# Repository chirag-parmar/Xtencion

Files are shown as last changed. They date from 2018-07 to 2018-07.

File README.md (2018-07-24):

#### The Design Methodology:
* The Xtencion band is equipped with a SHARP IR distance sensor to detect the different swipe gestures  and a 6DOF gyro module to read the wrist gestures. The band recognizes either individual gestures or a combination of them.
* After recognition it either navigates through the menu or triggers an external event based on the patter of the gestures. This way we provide a hassle free usability for the user.
* Since it is powered by a ESP32 (which has WiFi and Bluetooth onboard) connecting to other IoT devices is a breeze. The band controls other devices through a third-party service called IFTTT.
* IFTTT (stands for If This Then That) is a platform that enables interface between various devices. We plan to deploy Xtencion “Recipe” Blocks on their platform so that the user can customise external events. This way we provide extended functionality to the user.
* The band is powered by bendable lithium ion batteries which ensure maximum packing density and greater battery capacity. Such use of technology eliminates the biggest drawback of current smartwatches.

#### The Features:
* It is gesture controlled, so no more tapping the wrong thing and wasting time going back and attempting to tap again.
* It will reduce battery usage by nearly 50% by removing the touchscreen. The device will, additionally, use low power sensors.
* The device will have virtually an infinite number of features since new gestures can be added and each gesture can be customised.

#### The 3P Design Specifications:
* Power: It will last about 6 days without needing a charge according to our calculation.
* Precision: It has a range of 4 cm to 30 cm with an accuracy of 1mm.
* Protocols: The device uses HTTP to communicate with IoT devices and uses Bluetooth to get location data for location based gestures.

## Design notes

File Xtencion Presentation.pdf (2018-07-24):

# Xtencion

### A smarter smartwatch

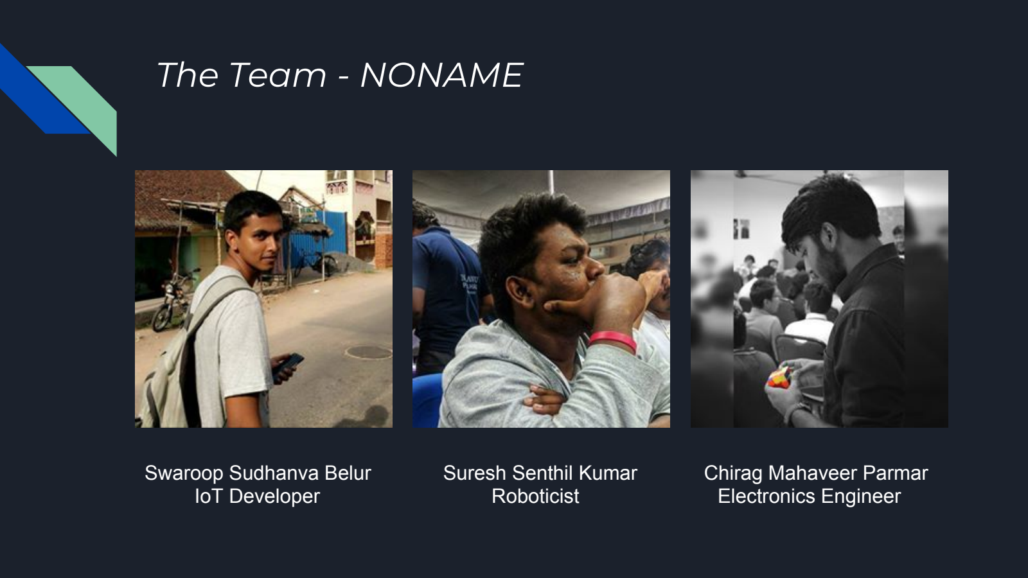
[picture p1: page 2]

The Team - NONAME

Swaroop Sudhanva Belur | Suresh Senthil Kumar | Chirag Mahaveer Parmar
IoT Developer | Roboticist | Electronics Engineer

## Connected Wearables

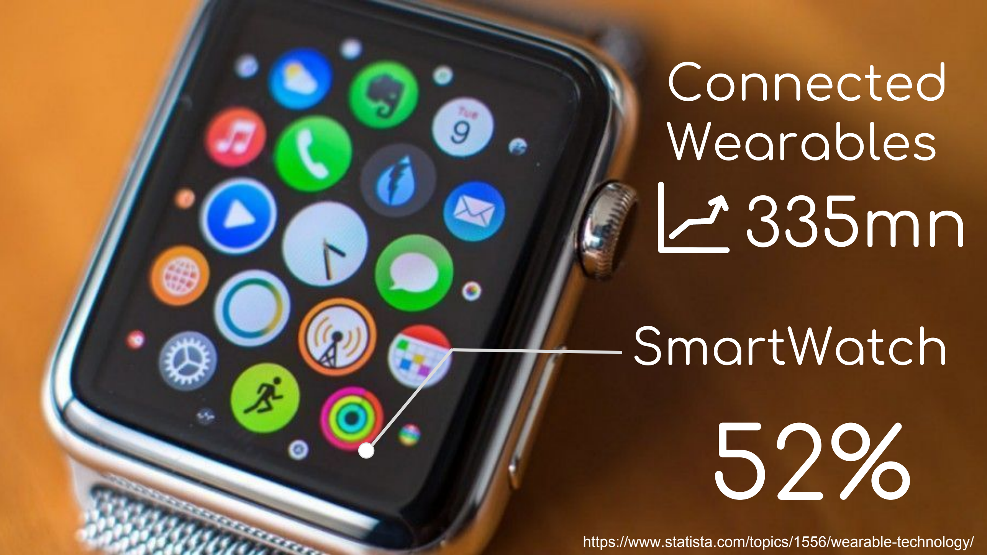
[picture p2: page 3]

## SmartWatch

335mn

52%

https://www.statista.com/topics/1556/wearable-technology/

The Problems with Smart Watches

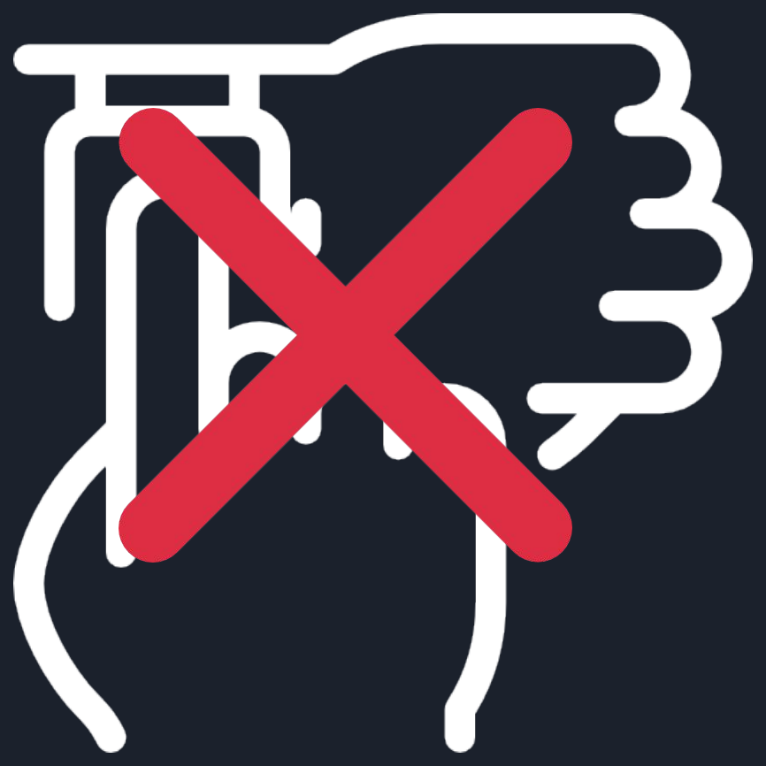
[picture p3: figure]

1

Difficult to navigate

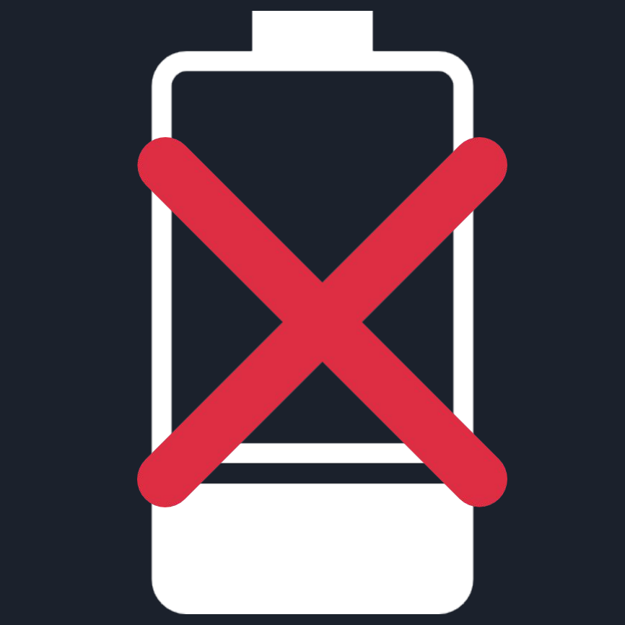
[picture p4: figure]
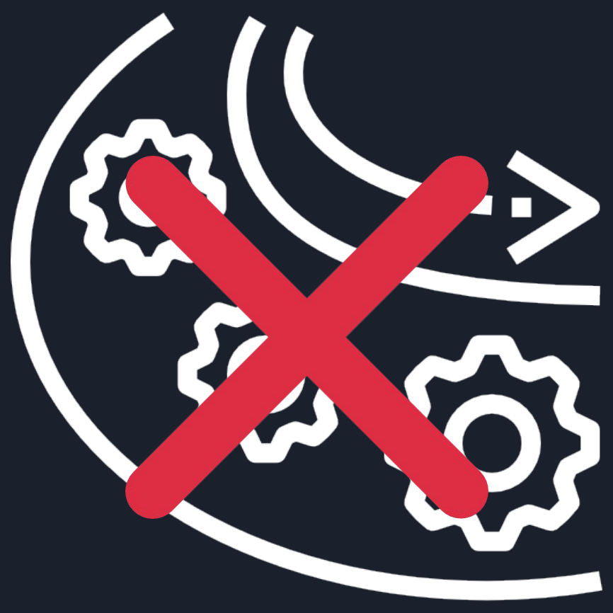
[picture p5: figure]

interface | 2 | Very - Short Battery Life | 3 | Missing Distinct Features compared to SmartPhones

https://www.cnet.com/videos/top-5-reasons-smartwatches-dont-sell/

The Validation - User Interviews

“My smartwatch is just like my phone, why did I waste money for something that I already have. I expected my
smartwatch to have extra
features in it”
- Mr. Rajesh, Self-Employed Entrepreneur

“It’s difficult to navigate through the menu on such a small screen. I would opt for a smart watch with buttons on it for easier use.”

- Ms. Lalitha, Fitness Freak

The Question

How can we make smartwatches a better tool and a better user experience for the end customer?

The Solution

We have built Xtencion, an intelligent wrist wear that has unparalleled functionality, improves the users’ productivity and efficiency while at the same time does not boggle the user with complicated user interfaces.

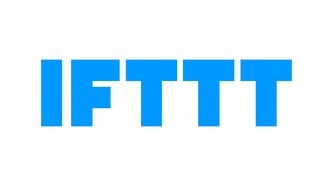
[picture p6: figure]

# How do we do it?

The Algorithm

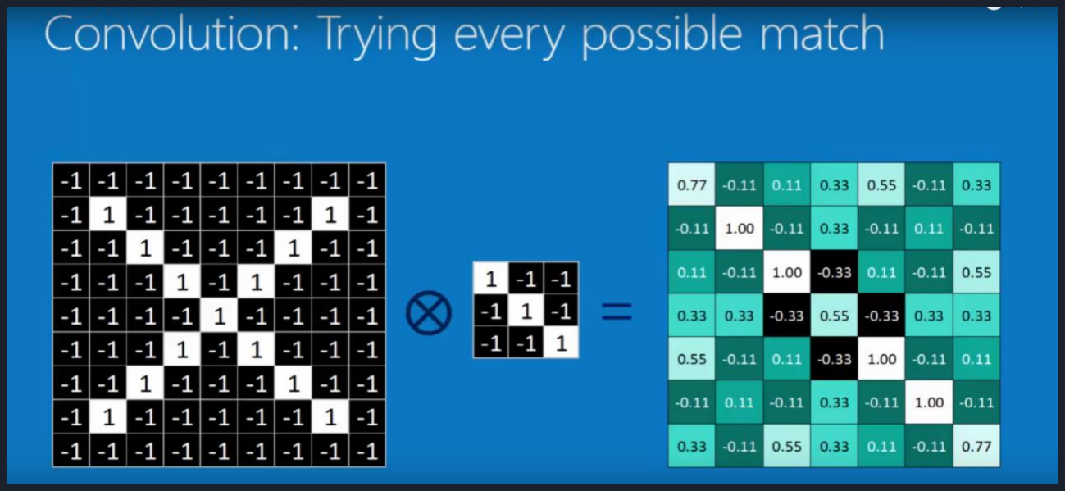
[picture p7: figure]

It is a signal processing
algorithm that uses a form of machine learning to
detect the hand gestures
using a predetermined
kernel. We use this kernel by performing convolution
of itself and the signal from the sharp rangefinder
sensor.

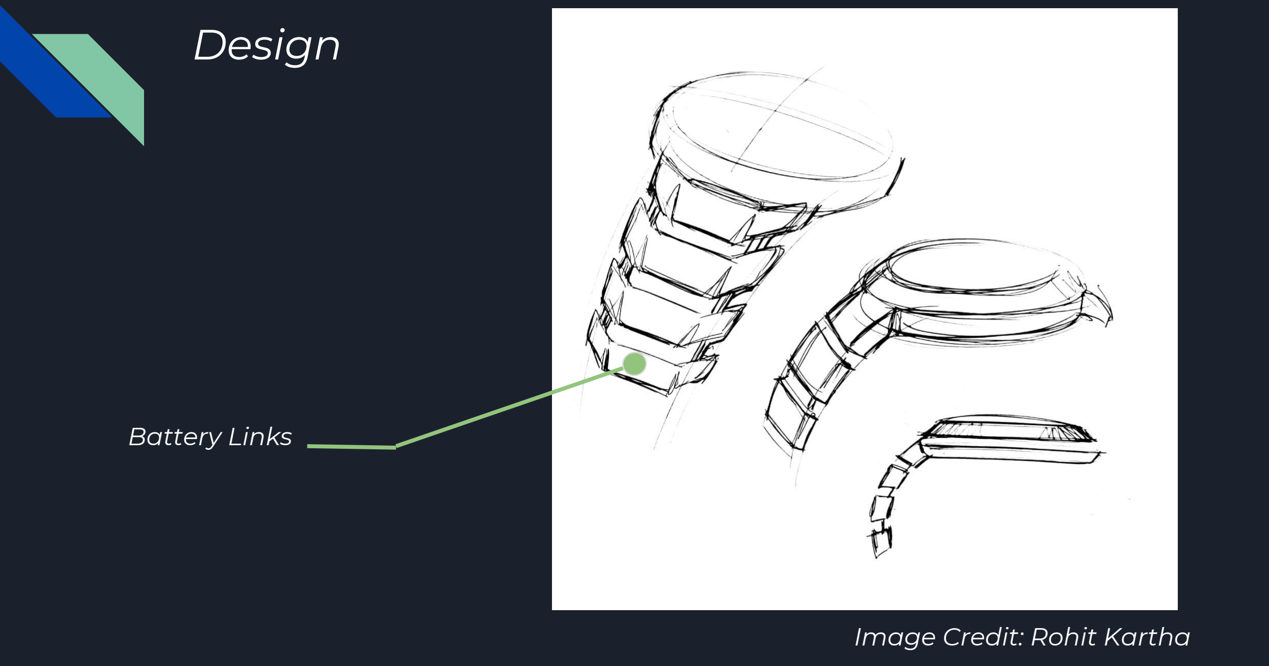
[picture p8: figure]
Design; Battery Links; Image Credit: Rohit Kartha

The 3X Design Features

It is gesture controlled, so no more tapping the wrong thing and wasting time going back and attempting to tap again.

It will reduce battery usage by nearly 10% by removing the touchscreen. The device will, additionally, use low power sensors.

The gestures are location based and time based so the user doesn’t have to remember different patterns of gestures

XTENDED USABILITY

XTENDED BATTERY

XTENDED FUNCTIONALITY

The 3P Design Specifications

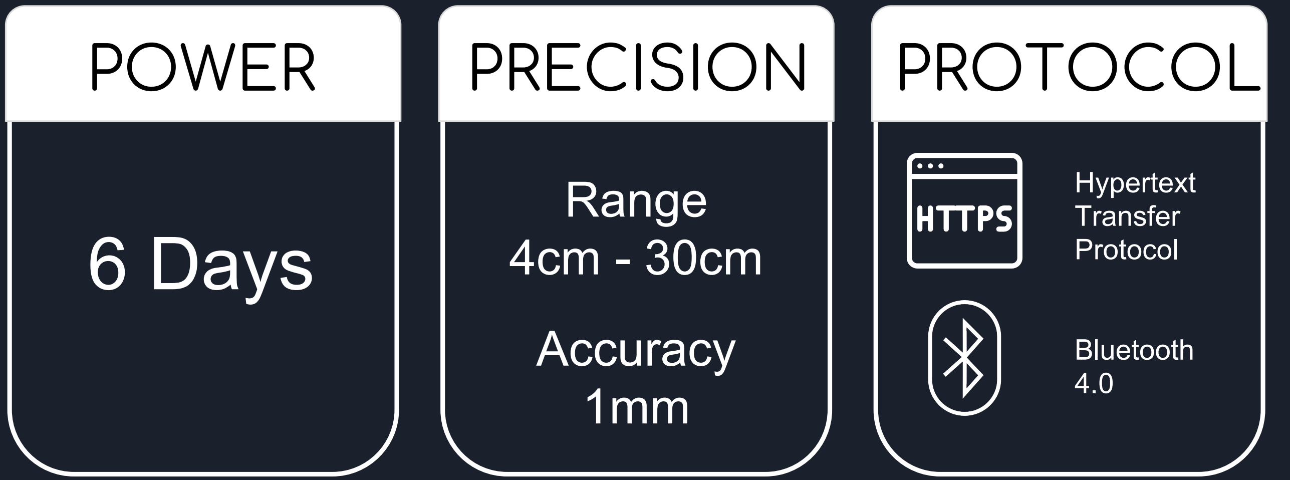
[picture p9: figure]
POWER; PRECISION; PROTOCOL; Range 4cm - 30cm; Accuracy 1mm; 6 Days; Hypertext Transfer Protocol; Bluetooth 4.0

* The price represent the design cost and not the cost of the product itself. If you were to design on your own it would cost you the above mentioned price.

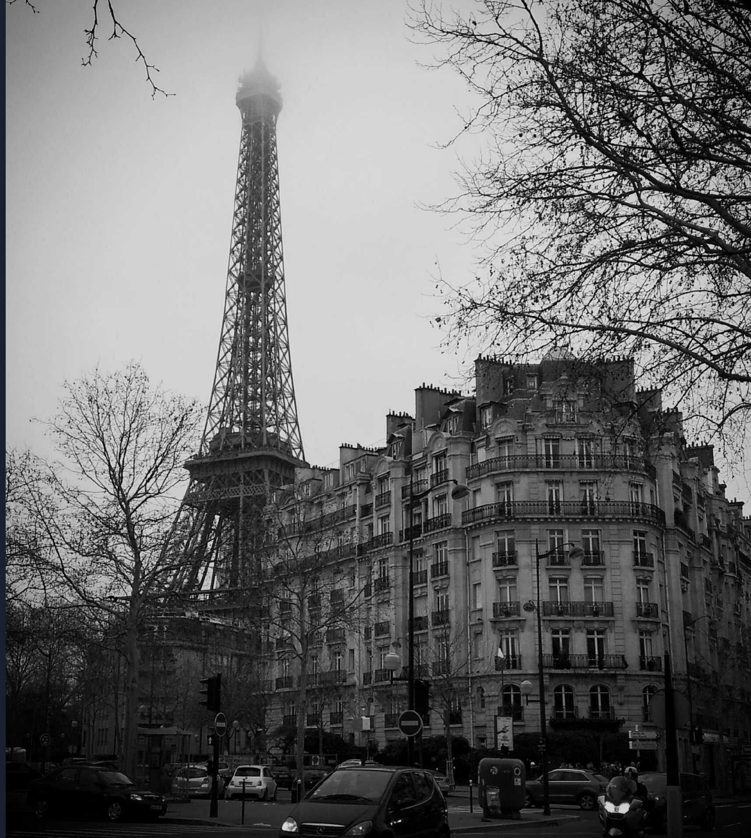
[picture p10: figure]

Thank You

Ask me anything!

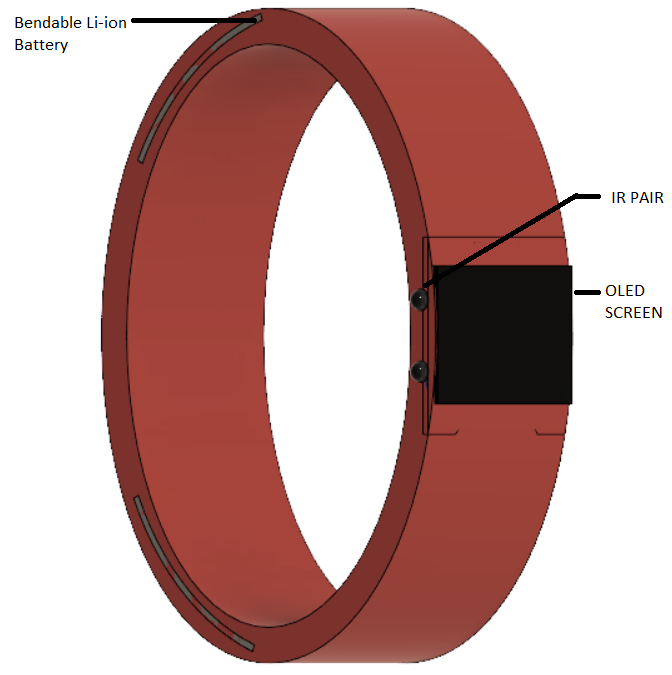
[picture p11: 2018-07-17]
images/Angled View Whole.png

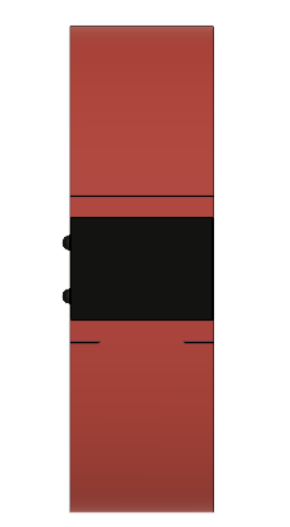
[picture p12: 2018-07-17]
images/Angled View IR.png

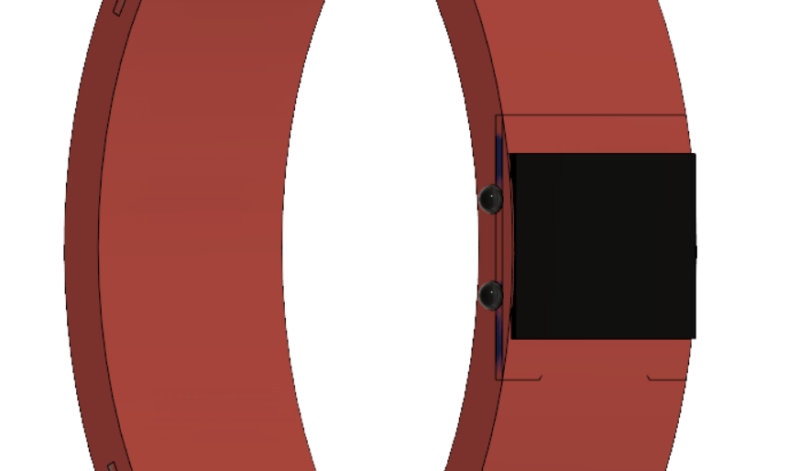
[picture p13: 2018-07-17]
images/Front View.png

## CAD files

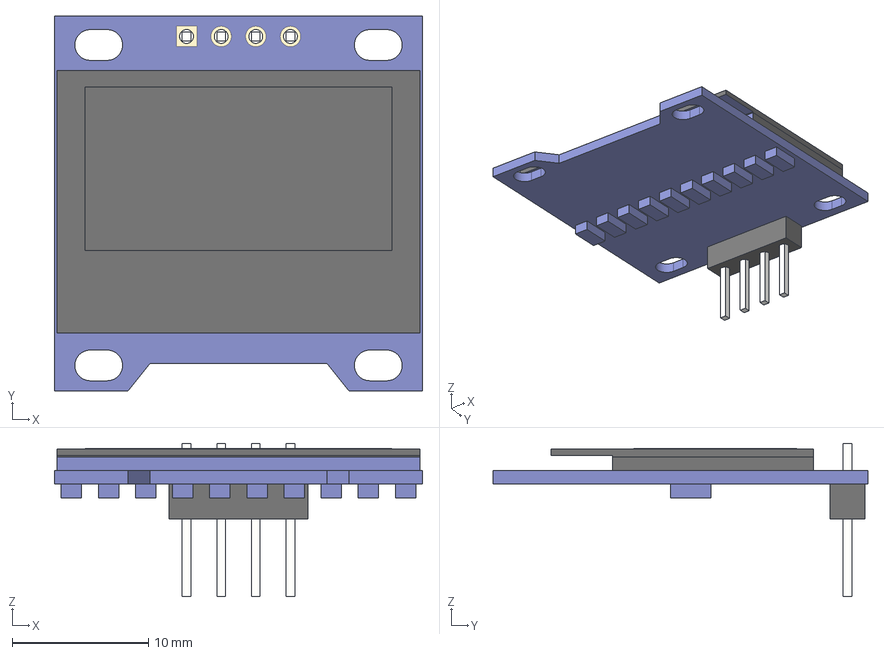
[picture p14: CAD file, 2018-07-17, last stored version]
128x64Oled v3.iges
27.0 x 27.5 x 11.2 mm

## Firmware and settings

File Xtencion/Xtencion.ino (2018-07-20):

#include <Wire.h>
#include "Kalman.h"
#include "SSD1306Wire.h"
#include <Adafruit_ADS1015.h>

//#define RESTRICT_PITCH // Comment out to restrict roll to ±90deg instead - please read: http://www.freescale.com/files/sensors/doc/app_note/AN3461.pdf

//-----------------Create Kalman Instances-------------------------//
Kalman kalmanX;
Kalman kalmanY;

//---------------------IMU constants and variables-----------------//
double accX, accY, accZ;
double gyroX, gyroY, gyroZ;
int16_t tempRaw;

double gyroXangle, gyroYangle; // Angle calculate using the gyro only
double compAngleX, compAngleY; // Calculated angle using a complementary filter
double kalAngleX, kalAngleY; // Calculated angle using a Kalman filter

uint32_t timer;
uint8_t i2cData[14]; // Buffer for I2C data

const uint8_t IMUAddress = 0x68; // AD0 is logic low on the PCB
const uint16_t I2C_TIMEOUT = 1000; // Used to check for errors in I2C communication

//---------------Sharp Sensor constants and Variables-------------//
Adafruit_ADS1115 ads;
int16_t sharp_adc;
float voltage;
double distance;
unsigned long distancetimer;
const int num_samples = 21;
int interval = 200;
double dist_q[num_samples];

//----------------OLED Display variables and constants-----------//
SSD1306Wire  display(0x3c, 0, 2);
unsigned long displaytimer;
//################################################ SETUP #####################################################//
void setup() {

  //----------------------Communication Setup ----------------------//
  Serial.begin(115200);
  Wire.begin(0, 2);
  Wire.setClock(400000L);

  //---------------------------IMU Setup---------------------------//
  i2cData[0] = 7; // Set the sample rate to 1000Hz - 8kHz/(7+1) = 1000Hz
  i2cData[1] = 0x00; // Disable FSYNC and set 260 Hz Acc filtering, 256 Hz Gyro filtering, 8 KHz sampling
  i2cData[2] = 0x00; // Set Gyro Full Scale Range to ±250deg/s
  i2cData[3] = 0x00; // Set Accelerometer Full Scale Range to ±2g
  while (i2cWrite(IMUAddress, 0x19, i2cData, 4, false)); // Write to all four registers at once
  while (i2cWrite(IMUAddress, 0x6B, 0x01, true)); // PLL with X axis gyroscope reference and disable sleep mode

  while (i2cRead(IMUAddress, 0x75, i2cData, 1));
  if (i2cData[0] != 0x71) { // Read "WHO_AM_I" register
    Serial.print(F("Error reading sensor"));
    while (1);
  }

  delay(100); // Wait for sensor to stabilize

  //----------------------Kalman Filter Setup---------------------//
  
  /* Set kalman and gyro starting angle */
  while (i2cRead(IMUAddress, 0x3B, i2cData, 6));
  accX = (i2cData[0] << 8) | i2cData[1];
  accY = (i2cData[2] << 8) | i2cData[3];
  accZ = (i2cData[4] << 8) | i2cData[5];
  
  #ifdef RESTRICT_PITCH // Eq. 25 and 26
    double roll  = atan2(accY, accZ) * RAD_TO_DEG;
    double pitch = atan(-accX / sqrt(accY * accY + accZ * accZ)) * RAD_TO_DEG;
  #else // Eq. 28 and 29
    double roll  = atan(accY / sqrt(accX * accX + accZ * accZ)) * RAD_TO_DEG;
    double pitch = atan2(-accX, accZ) * RAD_TO_DEG;
  #endif

  kalmanX.setAngle(roll); // Set starting angle
  kalmanY.setAngle(pitch);
  gyroXangle = roll;
  gyroYangle = pitch;
  compAngleX = roll;
  compAngleY = pitch;

  timer = micros();

  //-----------------------ADS 1115 Setup---------------------------//
  ads.begin();
  distancetimer = millis();
  for (int i=0;i<num_samples;i++)
  dist_q[i]=0.0;
  
  //-----------------------OLED Display Setup-----------------------//
  display.init();
  display.flipScreenVertically();
  display.setFont(ArialMT_Plain_10);
  displaytimer = millis();
}

//########################################## LOOP #########################################//
void loop() {
  //-----------------------Read IMU data--------------------//
  while (i2cRead(IMUAddress, 0x3B, i2cData, 14));
  accX = ((i2cData[0] << 8) | i2cData[1]) + 4000;
  accY = ((i2cData[2] << 8) | i2cData[3]) + 3500;
  accZ = ((i2cData[4] << 8) | i2cData[5]);
  tempRaw = (i2cData[6] << 8) | i2cData[7];
  gyroX = (i2cData[8] << 8) | i2cData[9];
  gyroY = (i2cData[10] << 8) | i2cData[11];
  gyroZ = (i2cData[12] << 8) | i2cData[13];

  //-------------------------Manipulate Data and Kalman Filter---------------------------//
  double dt = (double)(micros() - timer) / 1000000; // Calculate delta time
  timer = micros();

  #ifdef RESTRICT_PITCH // Eq. 25 and 26
    double roll  = atan2(accY, accZ) * RAD_TO_DEG;
    double pitch = atan(-accX / sqrt(accY * accY + accZ * accZ)) * RAD_TO_DEG;
  #else // Eq. 28 and 29
    double roll  = atan(accY / sqrt(accX * accX + accZ * accZ)) * RAD_TO_DEG;
    double pitch = atan2(-accX, accZ) * RAD_TO_DEG;
  #endif

  double gyroXrate = gyroX / 131.0; // Convert to deg/s
  double gyroYrate = gyroY / 131.0; // Convert to deg/s

  #ifdef RESTRICT_PITCH
    // This fixes the transition problem when the accelerometer angle jumps between -180 and 180 degrees
    if ((roll < -90 && kalAngleX > 90) || (roll > 90 && kalAngleX < -90)) {
      kalmanX.setAngle(roll);
      compAngleX = roll;
      kalAngleX = roll;
      gyroXangle = roll;
    } else
      kalAngleX = kalmanX.getAngle(roll, gyroXrate, dt); // Calculate the angle using a Kalman filter

    if (abs(kalAngleX) > 90)
      gyroYrate = -gyroYrate; // Invert rate, so it fits the restriced accelerometer reading
    kalAngleY = kalmanY.getAngle(pitch, gyroYrate, dt);
  #else
    // This fixes the transition problem when the accelerometer angle jumps between -180 and 180 degrees
    if ((pitch < -90 && kalAngleY > 90) || (pitch > 90 && kalAngleY < -90)) {
      kalmanY.setAngle(pitch);
      compAngleY = pitch;
      kalAngleY = pitch;
      gyroYangle = pitch;
    } else
      kalAngleY = kalmanY.getAngle(pitch, gyroYrate, dt); // Calculate the angle using a Kalman filter

    if (abs(kalAngleY) > 90)
      gyroXrate = -gyroXrate; // Invert rate, so it fits the restriced accelerometer reading
    kalAngleX = kalmanX.getAngle(roll, gyroXrate, dt); // Calculate the angle using a Kalman filter
  #endif

  gyroXangle += gyroXrate * dt; // Calculate gyro angle without any filter
  gyroYangle += gyroYrate * dt;
  //gyroXangle += kalmanX.getRate() * dt; // Calculate gyro angle using the unbiased rate
  //gyroYangle += kalmanY.getRate() * dt;

  compAngleX = 0.93 * (compAngleX + gyroXrate * dt) + 0.07 * roll; // Calculate the angle using a Complimentary filter
  compAngleY = 0.93 * (compAngleY + gyroYrate * dt) + 0.07 * pitch;

  // Reset the gyro angle when it has drifted too much
  if (gyroXangle < -180 || gyroXangle > 180)
    gyroXangle = kalAngleX;
  if (gyroYangle < -180 || gyroYangle > 180)
    gyroYangle = kalAngleY;

  //-------------------------Print Calculated Values----------------------------------//
//    Serial.print(accX); Serial.print("\t");
//    Serial.print(accY); Serial.print("\t");
//    Serial.print(accZ); Serial.print("\t");
//
//    Serial.print(roll); Serial.print("\t");
//    Serial.print(gyroXangle); Serial.print("\t");
//    Serial.print(compAngleX); Serial.print("\t");
//    Serial.print(kalAngleX); Serial.print("\t");
//
//    Serial.print("\t");
//
//    Serial.print(pitch); Serial.print("\t");
//    Serial.print(gyroYangle); Serial.print("\t");
//    Serial.print(compAngleY); Serial.print("\t");
//    Serial.print(kalAngleY); Serial.print("\t");
//
//    Serial.print("\t");
//
//    double temperature = (double)tempRaw / 340.0 + 36.53;
//    Serial.print(temperature); Serial.print("\t");
//
//    Serial.print("\t");
    
    
    sharp_adc = ads.readADC_SingleEnded(0);
    voltage = sharp_adc*0.1875/1000;
    distance = 13*pow(voltage,-1);
    if (((millis() - distancetimer) > interval) && distance > 4 && distance < 20){
      for (int  i= (num_samples-1); i>0; i--){
        dist_q[i] = dist_q[i-1];
      }
      dist_q[0] = distance;
      Serial.print("[ ");
      for (int i = (num_samples-1); i>= 0; i--){
        Serial.print(dist_q[i]);
        if (i!=0)Serial.print(", "); 
      }
      Serial.print(" ]");Serial.println("");
      
      double max = dist_q[0];
      int max_pos = 0;
      for (int i = 0; i < num_samples; i++)
      {
       if (dist_q[i] > max){
          max = dist_q[i];
          max_pos = i;
       }
      }
      
      double diff_forward = 0.0;
      double diff_backward = 0.0;
      Serial.print(diff_forward);Serial.print("\t");
      Serial.print(diff_backward);Serial.print("\t");
      //back swipe
      for (int i=0; i<max_pos ; i++){
        diff_backward += (dist_q[i+1] - dist_q[i]);
      }

      //forward swipe
      for (int i=max_pos; i<num_samples; i++){
        diff_forward += (dist_q[i-1] - dist_q[i]);
      }

      if (diff_forward > 4 && diff_backward > 4 && diff_forward < 7 && diff_backward <7)
        Serial.print("SHORT SWIPE SHORT SWIPE SHORT SWIPE SHORT SWIPE");
      else if(diff_forward >= 10 && diff_backward >= 10 && diff_forward < 20 && diff_backward <20)
        Serial.print("LONG SWIPE LONG SWIPE LONG SWIPE LONG SWIPE");
        
      distancetimer = millis();
      Serial.print(distance);Serial.print("\t");
      Serial.print(diff_forward);Serial.print("\t");
      Serial.print(diff_backward);Serial.print("\t");
      Serial.print(max);Serial.print("\t");
      Serial.print(max_pos);Serial.println("");
    }
//    else{
//      Serial.println(0);
//    }
    

    
    //printondisplay(roll, kalAngleX, pitch, kalAngleY, distance);
    
  //Serial.print("\r\n");
  delay(2);
}


//################################################## HELPER FUNCTIONS ##############################################//

//---------------------------I2C Communication Helper Functions-------------------------------//
uint8_t i2cWrite(uint8_t DeviceAddress, uint8_t registerAddress, uint8_t data, bool sendStop) {
  return i2cWrite(DeviceAddress, registerAddress, &data, 1, sendStop); // Returns 0 on success
}

uint8_t i2cWrite(uint8_t DeviceAddress, uint8_t registerAddress, uint8_t *data, uint8_t length, bool sendStop) {
  Wire.beginTransmission(DeviceAddress);
  Wire.write(registerAddress);
  Wire.write(data, length);
  uint8_t rcode = Wire.endTransmission(sendStop); // Returns 0 on success
  if (rcode) {
    Serial.print(F("i2cWrite failed: "));
    Serial.println(rcode);
  }
  return rcode; // See: http://arduino.cc/en/Reference/WireEndTransmission
}

uint8_t i2cRead(uint8_t DeviceAddress, uint8_t registerAddress, uint8_t *data, uint8_t nbytes) {
  uint32_t timeOutTimer;
  Wire.beginTransmission(DeviceAddress);
  Wire.write(registerAddress);
  uint8_t rcode = Wire.endTransmission(false); // Don't release the bus
  if (rcode) {
    Serial.print(F("i2cRead failed: "));
    Serial.println(rcode);
    return rcode; // See: http://arduino.cc/en/Reference/WireEndTransmission
  }
  Wire.requestFrom(DeviceAddress, nbytes, (uint8_t)true); // Send a repeated start and then release the bus after reading
  for (uint8_t i = 0; i < nbytes; i++) {
    if (Wire.available())
      data[i] = Wire.read();
    else {
      timeOutTimer = micros();
      while (((micros() - timeOutTimer) < I2C_TIMEOUT) && !Wire.available());
      if (Wire.available())
        data[i] = Wire.read();
      else {
        Serial.println(F("i2cRead timeout"));
        return 5; // This error value is not already taken by endTransmission
      }
    }
  }
  return 0; // Success
}

//------------------------------------OLED display helper functions-----------------------------------//
void printondisplay(double roll, double kalAngleX, double pitch, double kalAngleY, double distance){
    if (millis() - displaytimer > 500){
    display.clear();
    display.setFont(ArialMT_Plain_10);
    display.setTextAlignment(TEXT_ALIGN_LEFT);

    String temp1_String = String(roll, 2);
    String temp2_String = String(pitch, 2);
    String rollpitchString = temp1_String + " " + temp2_String + "\n";

    temp1_String = String(kalAngleX, 2);
    temp2_String = String(kalAngleY, 2);
    String kalmanString = temp1_String + " " + temp2_String + "\n";

    temp1_String = String(distance, 2);
    String distanceString = temp1_String + " cm" + "\n";
    display.drawString(0, 10, rollpitchString);
    display.drawString(0, 20, kalmanString);
    display.drawString(0, 30, distanceString);
    display.display();
    
    displaytimer = millis();
    }
}

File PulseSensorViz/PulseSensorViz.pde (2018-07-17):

    // Based on examples from Arduino's Graphing Tutorial and OscP5 documentation
    import processing.serial.*;
    Serial myPort; // The serial port
    int xPos = 1; // horizontal position of the graph
    float oldHeartrateHeight = 0; // for storing the previous reading

    void setup () {
    // set the window size:
    size(600, 400);
    frameRate(25);

    // List available serial ports.
    println(Serial.list());

    // Setup which serial port to use.
    // This line might change for different computers.
    myPort = new Serial(this, Serial.list()[0], 9600);

    // set inital background:
    background(0);
    }

    void draw () {
    }

    void serialEvent (Serial myPort) {
    // read the string from the serial port.
    String inString = myPort.readStringUntil('\n');

    if (inString != null) {
    // trim off any whitespace:
    inString = trim(inString);
    // convert to an int
    println(inString);
    int currentHeartrate = int(inString);

    // draw the Heartrate BPM Graph.
    float heartrateHeight = map(currentHeartrate, 0, 1023, 0, height);
    stroke(0,255,0);
    line(xPos - 1, height - oldHeartrateHeight, xPos, height - heartrateHeight);
    oldHeartrateHeight = heartrateHeight;
    // at the edge of the screen, go back to the beginning:
    if (xPos >= width) {
    xPos = 0;
    background(0);
    } else {
    // increment the horizontal position:
    xPos++;
   
    }
    }
    }

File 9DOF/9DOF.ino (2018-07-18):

/* MPU9250 Basic Example Code
 by: Kris Winer
 date: April 1, 2014
 license: Beerware - Use this code however you'd like. If you
 find it useful you can buy me a beer some time.
 Modified by Brent Wilkins July 19, 2016

 Demonstrate basic MPU-9250 functionality including parameterizing the register
 addresses, initializing the sensor, getting properly scaled accelerometer,
 gyroscope, and magnetometer data out. Added display functions to allow display
 to on breadboard monitor. Addition of 9 DoF sensor fusion using open source
 Madgwick and Mahony filter algorithms. Sketch runs on the 3.3 V 8 MHz Pro Mini
 and the Teensy 3.1.

 SDA and SCL should have external pull-up resistors (to 3.3V).
 10k resistors are on the EMSENSR-9250 breakout board.

 Hardware setup:
 MPU9250 Breakout --------- Arduino
 VDD ---------------------- 3.3V
 VDDI --------------------- 3.3V
 SDA ----------------------- A4
 SCL ----------------------- A5
 GND ---------------------- GND
 */

#include "quaternionFilters.h"
#include "MPU9250.h"

#define AHRS false         // Set to false for basic data read
#define SerialDebug true  // Set to true to get Serial output for debugging

// Pin definitions
int intPin = 12;  // These can be changed, 2 and 3 are the Arduinos ext int pins
int myLed  = 13;  // Set up pin 13 led for toggling

MPU9250 myIMU;

void setup()
{
  Wire.begin(0, 2);
  // TWBR = 12;  // 400 kbit/sec I2C speed
  Serial.begin(38400);

  // Set up the interrupt pin, its set as active high, push-pull
  pinMode(intPin, INPUT);
  digitalWrite(intPin, LOW);
  pinMode(myLed, OUTPUT);
  digitalWrite(myLed, HIGH);

  // Read the WHO_AM_I register, this is a good test of communication
  byte c = myIMU.readByte(MPU9250_ADDRESS, WHO_AM_I_MPU9250);
  Serial.print("MPU9250 "); Serial.print("I AM "); Serial.print(c, HEX);
  Serial.print(" I should be "); Serial.println(0x71, HEX);


  if (c == 0x71) // WHO_AM_I should always be 0x68
  {
    Serial.println("MPU9250 is online...");

    // Start by performing self test and reporting values
    myIMU.MPU9250SelfTest(myIMU.SelfTest);
    Serial.print("x-axis self test: acceleration trim within : ");
    Serial.print(myIMU.SelfTest[0],1); Serial.println("% of factory value");
    Serial.print("y-axis self test: acceleration trim within : ");
    Serial.print(myIMU.SelfTest[1],1); Serial.println("% of factory value");
    Serial.print("z-axis self test: acceleration trim within : ");
    Serial.print(myIMU.SelfTest[2],1); Serial.println("% of factory value");
    Serial.print("x-axis self test: gyration trim within : ");
    Serial.print(myIMU.SelfTest[3],1); Serial.println("% of factory value");
    Serial.print("y-axis self test: gyration trim within : ");
    Serial.print(myIMU.SelfTest[4],1); Serial.println("% of factory value");
    Serial.print("z-axis self test: gyration trim within : ");
    Serial.print(myIMU.SelfTest[5],1); Serial.println("% of factory value");

    // Calibrate gyro and accelerometers, load biases in bias registers
    myIMU.calibrateMPU9250(myIMU.gyroBias, myIMU.accelBias);
    myIMU.initMPU9250();
    Serial.println("MPU9250 initialized for active data mode....");


    byte d = myIMU.readByte(AK8963_ADDRESS, WHO_AM_I_AK8963);
    Serial.print("AK8963 "); Serial.print("I AM "); Serial.print(d, HEX);
    Serial.print(" I should be "); Serial.println(0x48, HEX);

    myIMU.initAK8963(myIMU.magCalibration);
    Serial.println("AK8963 initialized for active data mode....");
    if (SerialDebug)
    {
      //  Serial.println("Calibration values: ");
      Serial.print("X-Axis sensitivity adjustment value ");
      Serial.println(myIMU.magCalibration[0], 2);
      Serial.print("Y-Axis sensitivity adjustment value ");
      Serial.println(myIMU.magCalibration[1], 2);
      Serial.print("Z-Axis sensitivity adjustment value ");
      Serial.println(myIMU.magCalibration[2], 2);
    }
  } // if (c == 0x71)
  else
  {
    Serial.print("Could not connect to MPU9250: 0x");
    Serial.println(c, HEX);
    while(1) ; // Loop forever if communication doesn't happen
  }
}

void loop()
{
  // If intPin goes high, all data registers have new data
  // On interrupt, check if data ready interrupt
  if (myIMU.readByte(MPU9250_ADDRESS, INT_STATUS) & 0x01)
  {  
    myIMU.readAccelData(myIMU.accelCount);  // Read the x/y/z adc values
    myIMU.getAres();

    // Now we'll calculate the accleration value into actual g's
    // This depends on scale being set
    myIMU.ax = (float)myIMU.accelCount[0]*myIMU.aRes; // - accelBias[0];
    myIMU.ay = (float)myIMU.accelCount[1]*myIMU.aRes; // - accelBias[1];
    myIMU.az = (float)myIMU.accelCount[2]*myIMU.aRes; // - accelBias[2];

    myIMU.readGyroData(myIMU.gyroCount);  // Read the x/y/z adc values
    myIMU.getGres();

    // Calculate the gyro value into actual degrees per second
    // This depends on scale being set
    myIMU.gx = (float)myIMU.gyroCount[0]*myIMU.gRes;
    myIMU.gy = (float)myIMU.gyroCount[1]*myIMU.gRes;
    myIMU.gz = (float)myIMU.gyroCount[2]*myIMU.gRes;

    myIMU.readMagData(myIMU.magCount);  // Read the x/y/z adc values
    myIMU.getMres();
    // User environmental x-axis correction in milliGauss, should be
    // automatically calculated
    myIMU.magbias[0] = +470.;
    // User environmental x-axis correction in milliGauss TODO axis??
    myIMU.magbias[1] = +120.;
    // User environmental x-axis correction in milliGauss
    myIMU.magbias[2] = +125.;

    // Calculate the magnetometer values in milliGauss
    // Include factory calibration per data sheet and user environmental
    // corrections
    // Get actual magnetometer value, this depends on scale being set
    myIMU.mx = (float)myIMU.magCount[0]*myIMU.mRes*myIMU.magCalibration[0] -
               myIMU.magbias[0];
    myIMU.my = (float)myIMU.magCount[1]*myIMU.mRes*myIMU.magCalibration[1] -
               myIMU.magbias[1];
    myIMU.mz = (float)myIMU.magCount[2]*myIMU.mRes*myIMU.magCalibration[2] -
               myIMU.magbias[2];
  } // if (readByte(MPU9250_ADDRESS, INT_STATUS) & 0x01)

  // Must be called before updating quaternions!
  myIMU.updateTime();
  MahonyQuaternionUpdate(myIMU.ax, myIMU.ay, myIMU.az, myIMU.gx*DEG_TO_RAD,
                         myIMU.gy*DEG_TO_RAD, myIMU.gz*DEG_TO_RAD, myIMU.my,
                         myIMU.mx, myIMU.mz, myIMU.deltat);
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

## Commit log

2018-07-18 9DOF sensor and Sharp sensor working independently
2018-07-19 combined working of both sensors
2018-07-19 All three devices working together on i2c bus
2018-07-24 Swipe control completed
    [128x64Oled v3.iges]
